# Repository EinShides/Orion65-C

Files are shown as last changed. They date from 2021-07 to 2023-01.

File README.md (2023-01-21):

A 65% keyboard PCB that supports standard and arrow key blocker layouts (such as the kbd67) and stepped caps lock. The PCB also features a flex cut for a softer typing experience. Uses USB type C and has a ESD protection diode. PCB is tested and working. A matching case model can be found here via the fusion 360 link: https://a360.co/2X7CGb7 (Though there is a name engraving for myself in the top right that needs to be changed if you don't want it).

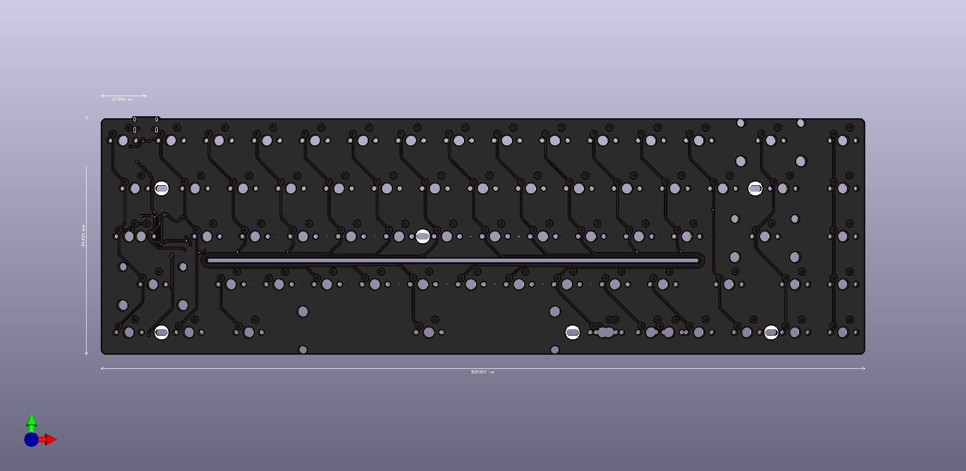
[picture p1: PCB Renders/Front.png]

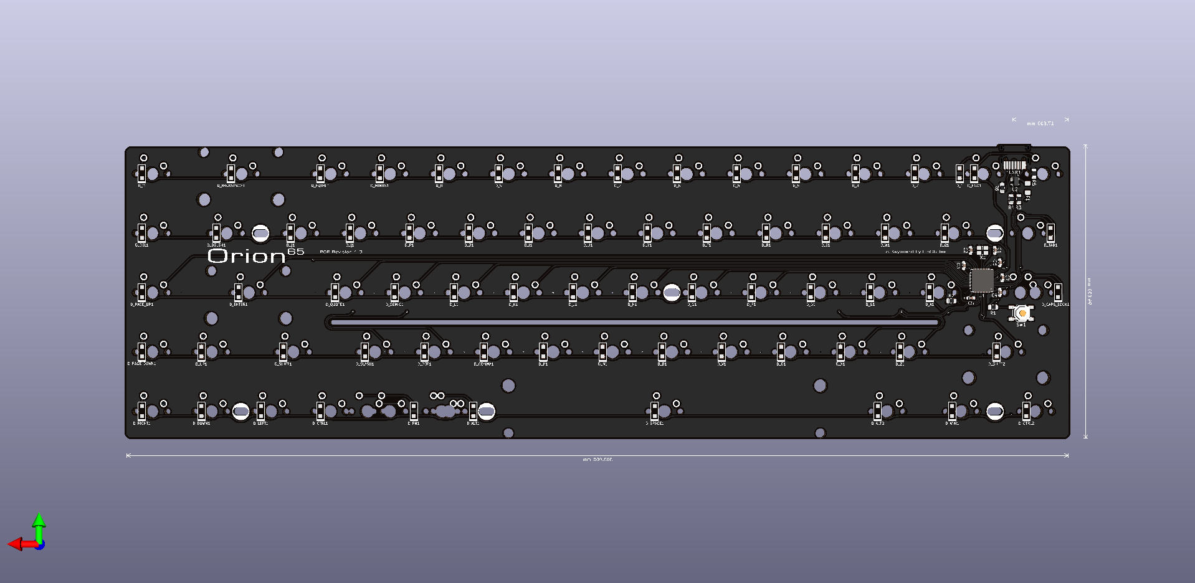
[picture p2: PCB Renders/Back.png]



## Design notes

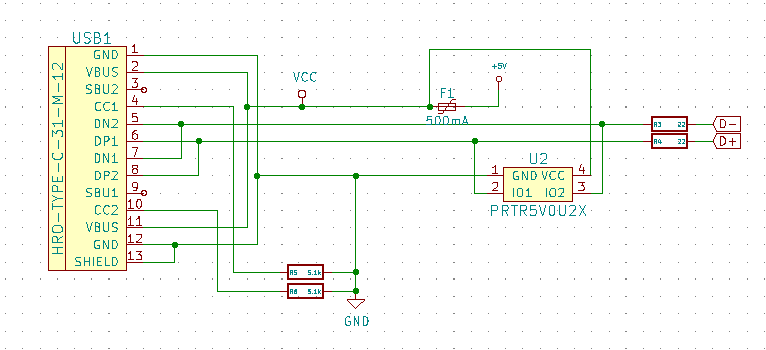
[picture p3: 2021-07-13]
Schematic/Typce C USB.PNG

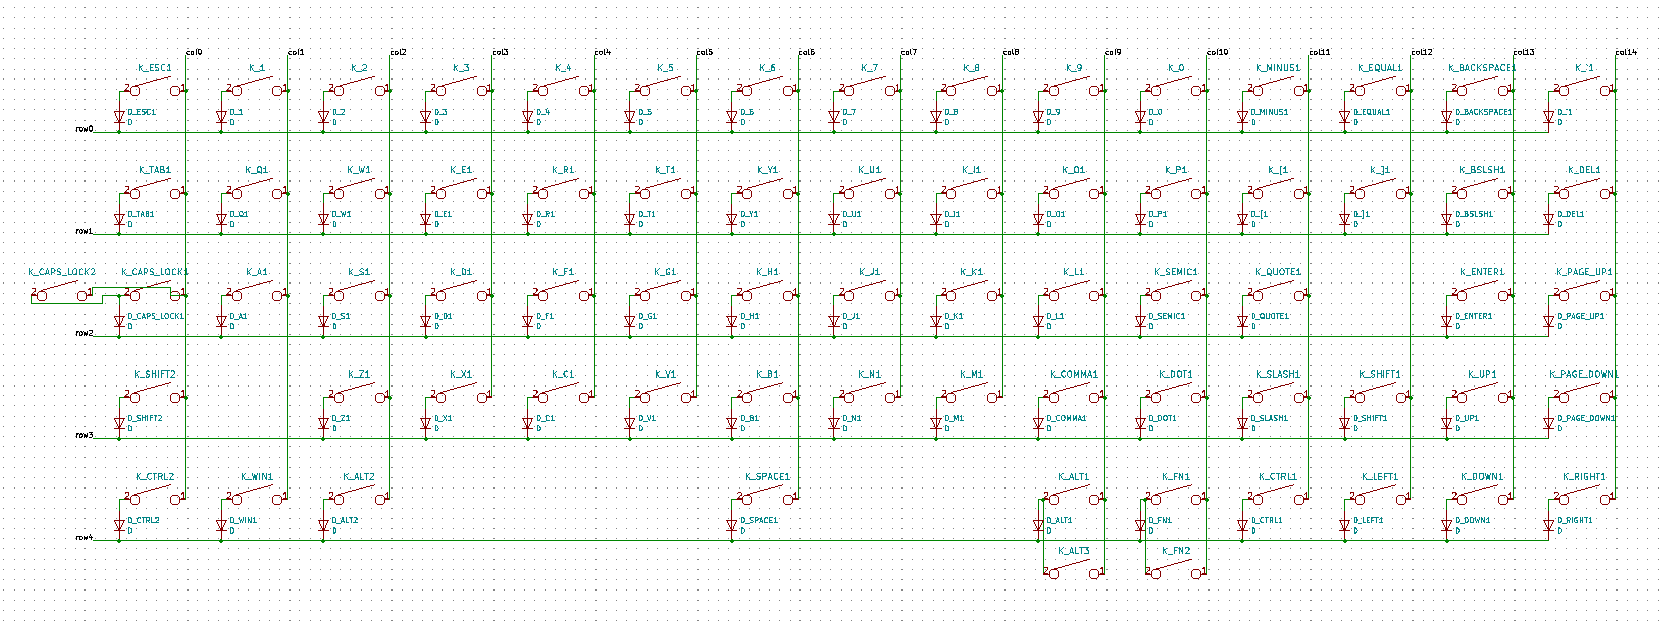
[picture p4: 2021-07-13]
Schematic/Switch Matrix.PNG

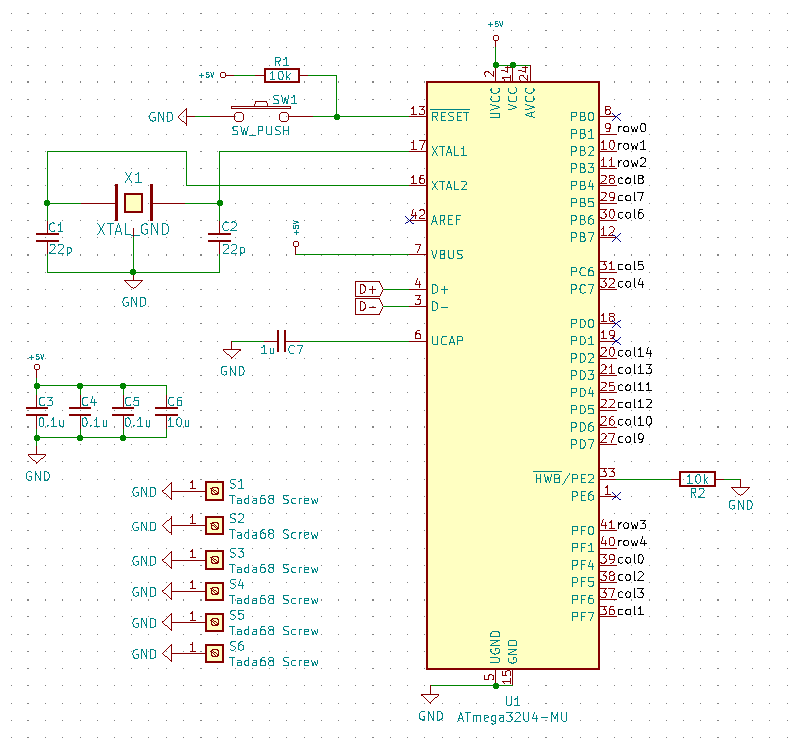
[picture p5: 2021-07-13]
Schematic/MCU.PNG

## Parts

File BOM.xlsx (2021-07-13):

PCB Part Reference | Quantity per PCB | Component | Footprint | Manufacturer | Manufacturer Part Number | Description
U1 | 1 | Atmega32U4-MU Microcontroller | QFN-44-1EP_7x7mm_P0.5mm_EP5.2x5.2mm | Microchip Technology | ATMEGA32U4-MU | AVR AVR® ATmega Microcontroller IC 8-Bit 16MHz 32KB (16K x 16) FLASH 44-VQFN (7x7)
U2 | 1 | PRTR5V0U2X ESD Protection IC | SOT143B | Nexperia USA Inc. | PRTR5V0U2X,215 | Clamp Ipp Tvs Diode Surface Mount SOT-143B
X1 | 1 | Crystal, 3.2 x 2.5mm, 16MHz | crystal_FA238-TSX3225 | EPSON | FA-238 16.0000MB-C3 | 16MHz ±50ppm Crystal 18pF 80 Ohms 4-SMD, No Lead
F1 | 1 | Polyfuse, 500mA hold, 1A trip | Fuse_1206_3216Metric_Pad1.42x1.75mm_HandSolder | Littelfuse Inc. | 1206L050/24WR | Polymeric PTC Resettable Fuse 24V 500mA Ih Surface Mount 1206 (3216 Metric), Concave
USB1 | 1 | USB Type C Port (One Row Design) | HRO-TYPE-C-31-M-12-HandSoldering | Korean Hroparts Elec | TYPE-C-31-M-12 | Type C Female 24 8.94*7.3mm USB Connectors RoHS
C1, C2 | 2 | 22pF Capacitor, Ceramic, 15V or more | C_0603_1608Metric_Pad1.05x0.95mm_HandSolder | Yageo | CC0603JRNPO9BN220 | 22pF ±5% 50V Ceramic Capacitor C0G, NP0 0603 (1608 Metric)
C3, C5, C6 | 4 | 0.1uF (100nF) Capacitor, Ceramic, 15V or more | C_0603_1608Metric_Pad1.05x0.95mm_HandSolder | KEMET | C0603C104J4RACTU | 0.1µF ±5% 16V Ceramic Capacitor X7R 0603 (1608 Metric)
C7 | 1 | 1uF Capacitor, Ceramic, 15V or more | C_0603_1608Metric_Pad1.05x0.95mm_HandSolder | Yageo | CC0603ZRY5V7BB105 | 1µF -20%, +80% 16V Ceramic Capacitor Y5V (F) 0603 (1608 Metric)
C4 | 1 | 10uF Capacitor, Ceramic, 15V or more | C_0603_1608Metric_Pad1.05x0.95mm_HandSolder | Yageo | CC0603MRX5R8BB106 | 10µF ±20% 25V Ceramic Capacitor X5R 0603 (1608 Metric)
R5, R6 | 2 | 5.1k Ohm Resistor, Generic | R_0805_2012Metric_Pad1.15x1.40mm_HandSolder | Bourns Inc. | CR0805-FX-5101ELF | 5.1 kOhms ±1% 0.125W, 1/8W Chip Resistor 0805 (2012 Metric) Moisture Resistant Thick Film
R3, R4 | 2 | 22 Ohm Resistor, Generic | R_0805_2012Metric_Pad1.15x1.40mm_HandSolder | Stackpole Electronics Inc | RMCF0805JT22R0 | 22 Ohms ±5% 0.125W, 1/8W Chip Resistor 0805 (2012 Metric) Automotive AEC-Q200 Thick Film
R1, R2 | 2 | 10k Ohm Resistor, Generic | R_0805_2012Metric_Pad1.15x1.40mm_HandSolder | Stackpole Electronics Inc | RMCF0805JT10K0 | 10 kOhms ±5% 0.125W, 1/8W Chip Resistor 0805 (2012 Metric) Automotive AEC-Q200 Thick Film
All "D" References | 68 | Diode, Generic | D_SOD123_hand | Diodes Incorporated | 1N4148W-13-F | Diode Standard 100V 150mA Surface Mount SOD-123
SW1 | 1 | Button | SW_SPST_TL3342 | E-Switch | TL3342F260QG | Tactile Switch SPST-NO Top Actuated Surface Mount

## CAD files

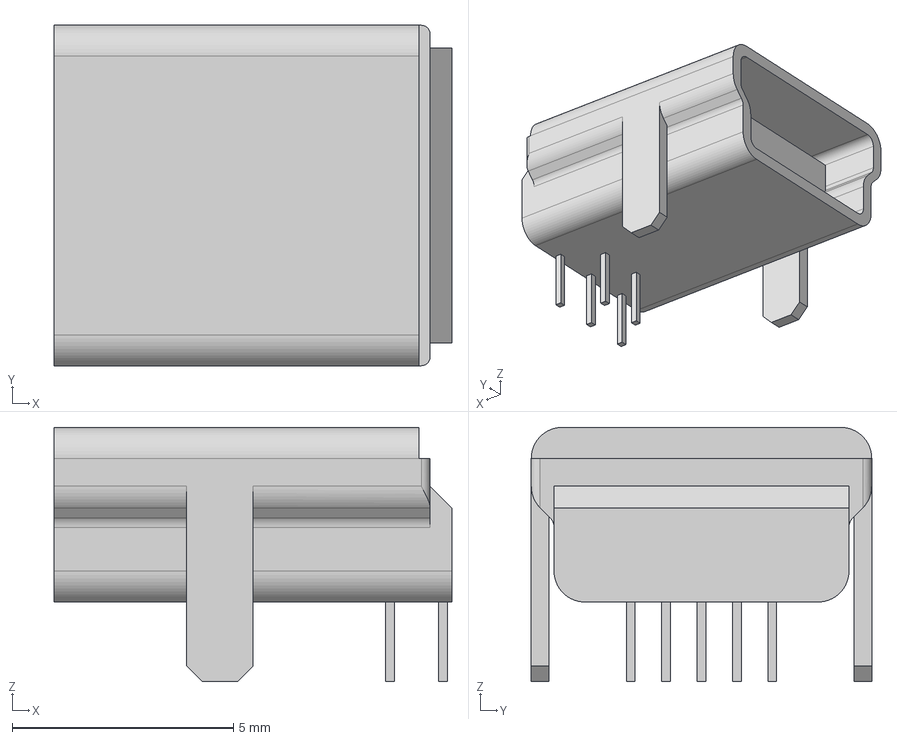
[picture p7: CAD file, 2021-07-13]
random-keyboard-parts.pretty-master/Molex-0548190519.step
9.00 x 7.70 x 5.75 mm

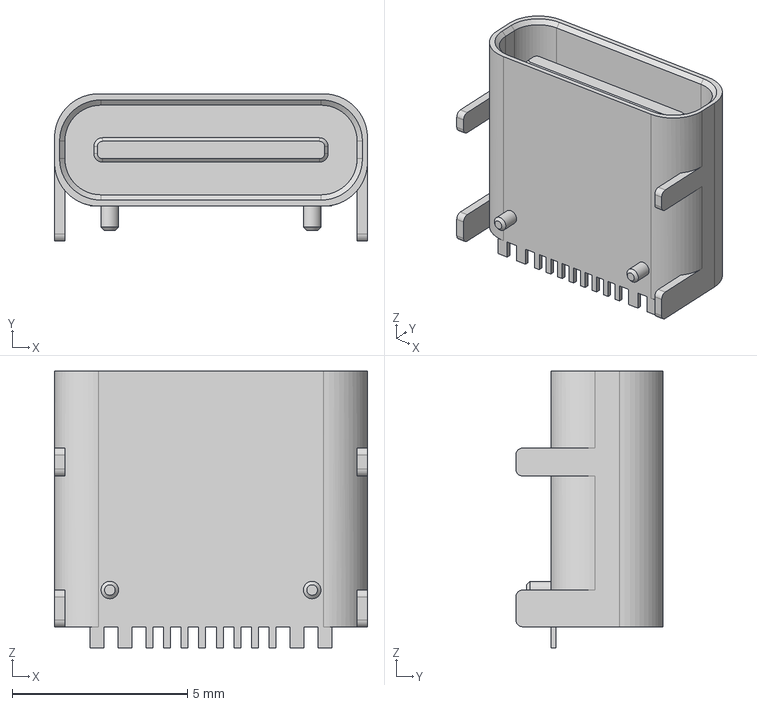
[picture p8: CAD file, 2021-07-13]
Type-C.pretty-master/HRO TYPE-C-31-M-12.step
8.94 x 4.21 x 7.90 mm

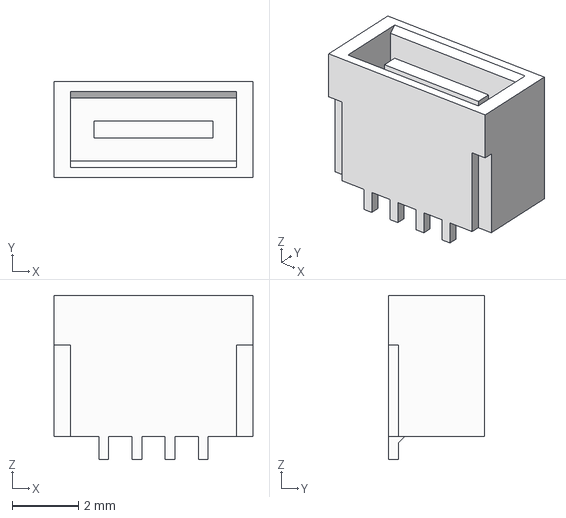
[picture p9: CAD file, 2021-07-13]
random-keyboard-parts.pretty-master/JST-SR-4.step
6.00 x 2.90 x 4.95 mm

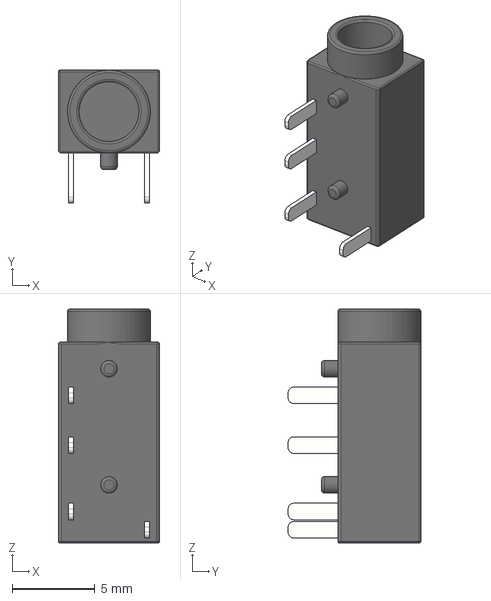
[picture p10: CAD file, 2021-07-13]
random-keyboard-parts.pretty-master/PJ-3200B.step
6.10 x 8.00 x 14.1 mm

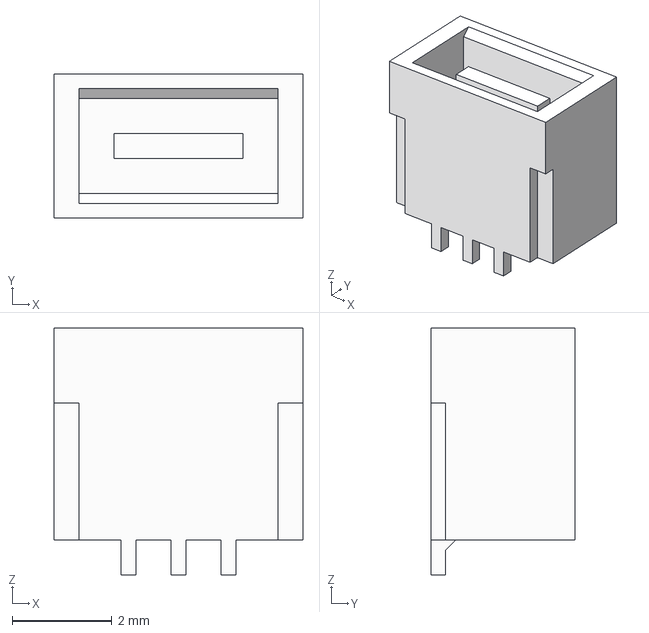
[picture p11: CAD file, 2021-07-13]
random-keyboard-parts.pretty-master/JST-SR-3.step
5.00 x 2.90 x 4.95 mm

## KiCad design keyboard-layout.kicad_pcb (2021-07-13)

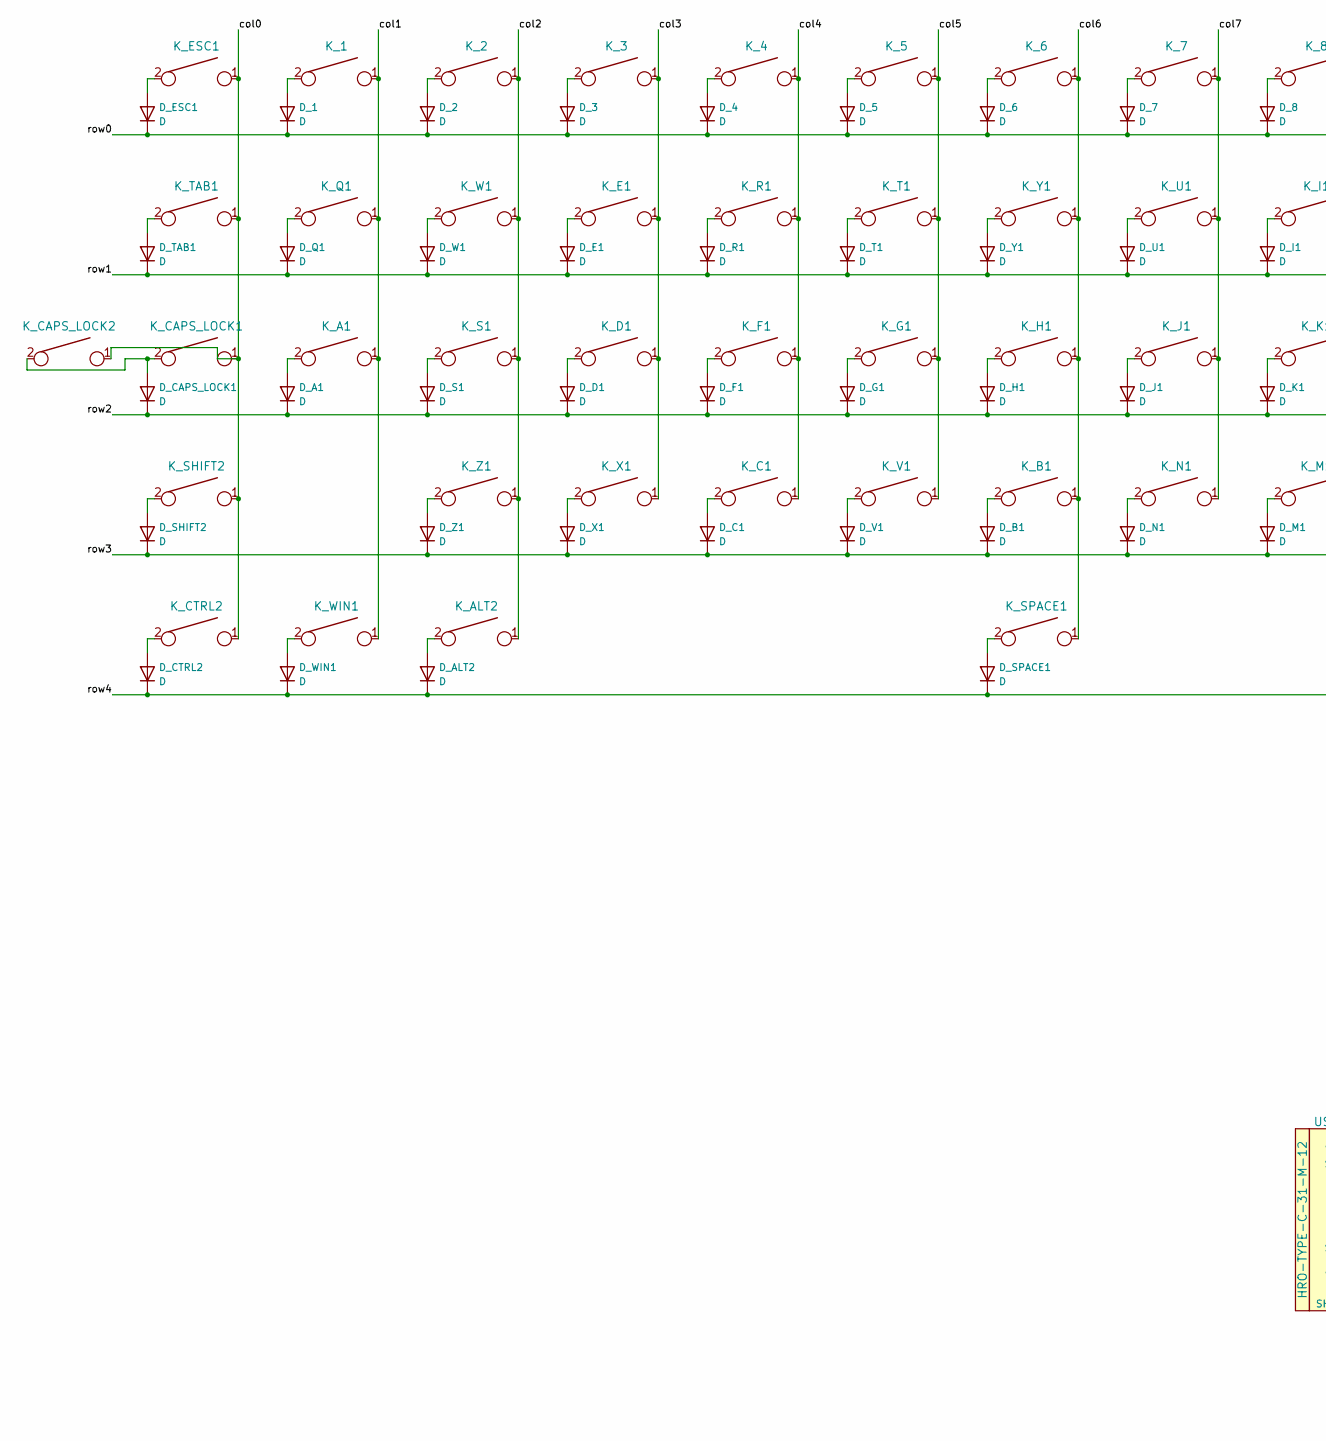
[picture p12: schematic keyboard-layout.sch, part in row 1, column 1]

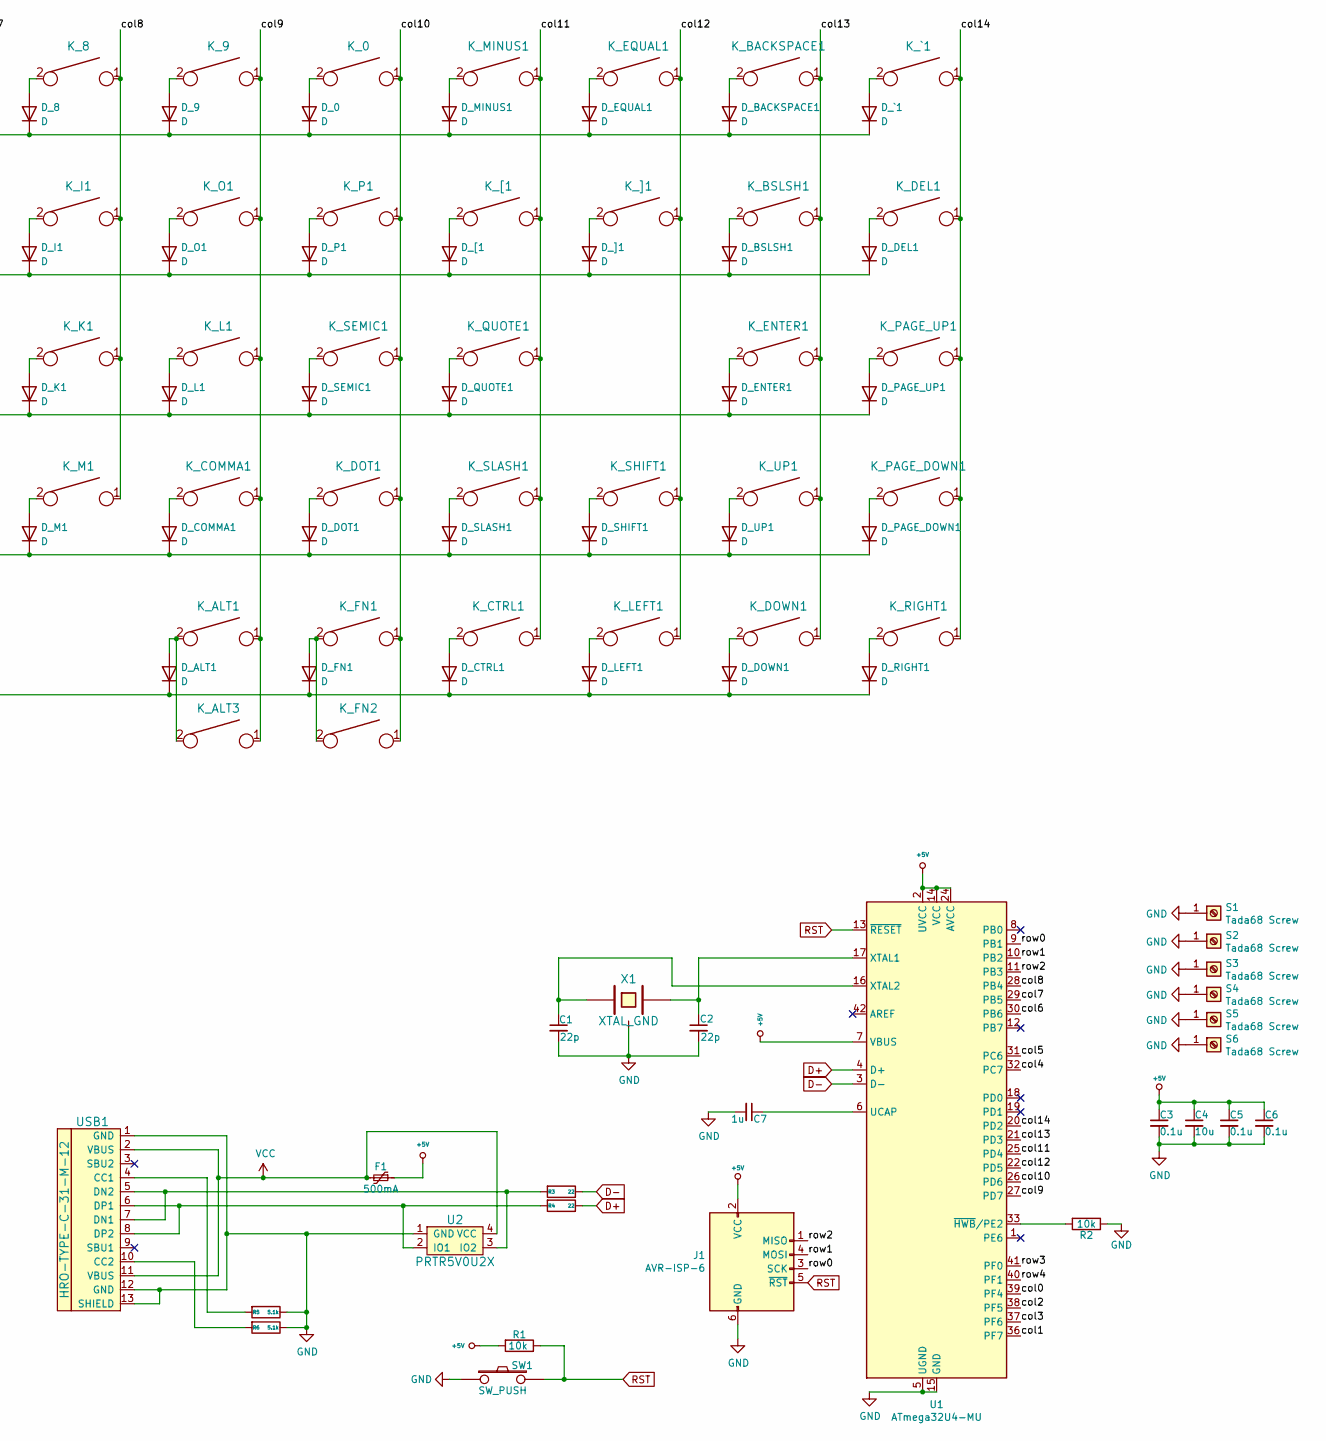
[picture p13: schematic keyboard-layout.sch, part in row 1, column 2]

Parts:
C1, C2: 22p; C_0603_1608Metric_Pad1.05x0.95mm_HandSolder; LCSC C1653
C3, C5, C6: 0.1u; C_0603_1608Metric_Pad1.05x0.95mm_HandSolder; LCSC C24452
C4: 10u; C_0603_1608Metric_Pad1.05x0.95mm_HandSolder; LCSC C96446
C7: 1u; C_0603_1608Metric_Pad1.05x0.95mm_HandSolder; LCSC C15849
D_0, D_1, D_2, D_3, D_4, D_5, D_6, D_7, D_8, D_9: D; D_SOD123_hand; LCSC C64898
D_A1: D; D_SOD123_hand; LCSC C64898
D_ALT1, D_ALT2: D; D_SOD123_hand; LCSC C64898
D_B1: D; D_SOD123_hand; LCSC C64898
D_BACKSPACE1: D; D_SOD123_hand; LCSC C64898
D_BSLSH1: D; D_SOD123_hand; LCSC C64898
D_C1: D; D_SOD123_hand; LCSC C64898
D_CAPS_LOCK1: D; D_SOD123_hand; LCSC C64898
D_COMMA1: D; D_SOD123_hand; LCSC C64898
D_CTRL1, D_CTRL2: D; D_SOD123_hand; LCSC C64898
D_D1: D; D_SOD123_hand; LCSC C64898
D_DEL1: D; D_SOD123_hand; LCSC C64898
D_DOT1: D; D_SOD123_hand; LCSC C64898
D_DOWN1: D; D_SOD123_hand; LCSC C64898
D_E1: D; D_SOD123_hand; LCSC C64898
D_ENTER1: D; D_SOD123_hand; LCSC C64898
D_EQUAL1: D; D_SOD123_hand; LCSC C64898
D_ESC1: D; D_SOD123_hand; LCSC C64898
D_F1: D; D_SOD123_hand; LCSC C64898
D_FN1: D; D_SOD123_hand; LCSC C64898
D_G1: D; D_SOD123_hand; LCSC C64898
D_H1: D; D_SOD123_hand; LCSC C64898
D_I1: D; D_SOD123_hand; LCSC C64898
D_J1: D; D_SOD123_hand; LCSC C64898
D_K1: D; D_SOD123_hand; LCSC C64898
D_L1: D; D_SOD123_hand; LCSC C64898
D_LEFT1: D; D_SOD123_hand; LCSC C64898
D_M1: D; D_SOD123_hand; LCSC C64898
D_MINUS1: D; D_SOD123_hand; LCSC C64898
D_N1: D; D_SOD123_hand; LCSC C64898
D_O1: D; D_SOD123_hand; LCSC C64898
D_P1: D; D_SOD123_hand; LCSC C64898
D_PAGE_DOWN1: D; D_SOD123_hand; LCSC C64898
D_PAGE_UP1: D; D_SOD123_hand; LCSC C64898
D_Q1: D; D_SOD123_hand; LCSC C64898
D_QUOTE1: D; D_SOD123_hand; LCSC C64898
D_R1: D; D_SOD123_hand; LCSC C64898
D_RIGHT1: D; D_SOD123_hand; LCSC C64898
D_S1: D; D_SOD123_hand; LCSC C64898
D_SEMIC1: D; D_SOD123_hand; LCSC C64898
D_SHIFT1, D_SHIFT2: D; D_SOD123_hand; LCSC C64898
D_SLASH1: D; D_SOD123_hand; LCSC C64898
D_SPACE1: D; D_SOD123_hand; LCSC C64898
D_T1: D; D_SOD123_hand; LCSC C64898
D_TAB1: D; D_SOD123_hand; LCSC C64898
D_U1: D; D_SOD123_hand; LCSC C64898
D_UP1: D; D_SOD123_hand; LCSC C64898
D_V1: D; D_SOD123_hand; LCSC C64898
D_W1: D; D_SOD123_hand; LCSC C64898
D_WIN1: D; D_SOD123_hand; LCSC C64898
D_X1: D; D_SOD123_hand; LCSC C64898
D_Y1: D; D_SOD123_hand; LCSC C64898
D_Z1: D; D_SOD123_hand; LCSC C64898
D_[1: D; D_SOD123_hand; LCSC C64898
D_]1: D; D_SOD123_hand; LCSC C64898
D_`1: D; D_SOD123_hand; LCSC C64898
F1: 500mA; Fuse_1206_3216Metric_Pad1.42x1.75mm_HandSolder; LCSC C70076
J1: AVR-ISP-6; isp_standard
K_0, K_1, K_2, K_3, K_4, K_5, K_6, K_7, K_8, K_9: KEYSW; MXOnly-1U-NoLED
K_A1: KEYSW; MXOnly-1U-NoLED
K_ALT1: KEYSW; MXOnly-1U-NoLED
K_ALT2, K_ALT3: KEYSW; MXOnly-1.25U-NoLED
K_B1: KEYSW; MXOnly-1U-NoLED
K_BACKSPACE1: KEYSW; MXOnly-2U-NoLED
K_BSLSH1: KEYSW; MXOnly-1.5U-NoLED
K_C1: KEYSW; MXOnly-1U-NoLED
K_CAPS_LOCK1: KEYSW; MXOnly-1.75U-NoLED
K_CAPS_LOCK2: KEYSW; MXOnly-1.25U-NoLED
K_COMMA1: KEYSW; MXOnly-1U-NoLED
K_CTRL1: KEYSW; MXOnly-1U-NoLED
K_CTRL2: KEYSW; MXOnly-1.25U-NoLED
K_D1: KEYSW; MXOnly-1U-NoLED
K_DEL1: KEYSW; MXOnly-1U-NoLED
K_DOT1: KEYSW; MXOnly-1U-NoLED
K_DOWN1: KEYSW; MXOnly-1U-NoLED
K_E1: KEYSW; MXOnly-1U-NoLED
K_ENTER1: KEYSW; MXOnly-2.25U-NoLED
K_EQUAL1: KEYSW; MXOnly-1U-NoLED
K_ESC1: KEYSW; MXOnly-1U-NoLED
K_F1: KEYSW; MXOnly-1U-NoLED
K_FN1: KEYSW; MXOnly-1U-NoLED
K_FN2: KEYSW; MXOnly-1.25U-NoLED
K_G1: KEYSW; MXOnly-1U-NoLED
K_H1: KEYSW; MXOnly-1U-NoLED
K_I1: KEYSW; MXOnly-1U-NoLED
K_J1: KEYSW; MXOnly-1U-NoLED
K_K1: KEYSW; MXOnly-1U-NoLED
K_L1: KEYSW; MXOnly-1U-NoLED
K_LEFT1: KEYSW; MXOnly-1U-NoLED
K_M1: KEYSW; MXOnly-1U-NoLED
K_MINUS1: KEYSW; MXOnly-1U-NoLED
K_N1: KEYSW; MXOnly-1U-NoLED
K_O1: KEYSW; MXOnly-1U-NoLED
K_P1: KEYSW; MXOnly-1U-NoLED
K_PAGE_DOWN1: KEYSW; MXOnly-1U-NoLED
K_PAGE_UP1: KEYSW; MXOnly-1U-NoLED
K_Q1: KEYSW; MXOnly-1U-NoLED
K_QUOTE1: KEYSW; MXOnly-1U-NoLED
K_R1: KEYSW; MXOnly-1U-NoLED
K_RIGHT1: KEYSW; MXOnly-1U-NoLED
K_S1: KEYSW; MXOnly-1U-NoLED
K_SEMIC1: KEYSW; MXOnly-1U-NoLED
K_SHIFT1: KEYSW; MXOnly-1.75U-NoLED
K_SHIFT2: KEYSW; MXOnly-2.25U-NoLED
K_SLASH1: KEYSW; MXOnly-1U-NoLED
K_SPACE1: KEYSW; MXOnly-6.25U-ReversedStabilizers-NoLED
K_T1: KEYSW; MXOnly-1U-NoLED
K_TAB1: KEYSW; MXOnly-1.5U-NoLED
K_U1: KEYSW; MXOnly-1U-NoLED
K_UP1: KEYSW; MXOnly-1U-NoLED
K_V1: KEYSW; MXOnly-1U-NoLED
K_W1: KEYSW; MXOnly-1U-NoLED
K_WIN1: KEYSW; MXOnly-1.25U-NoLED
K_X1: KEYSW; MXOnly-1U-NoLED
K_Y1: KEYSW; MXOnly-1U-NoLED
K_Z1: KEYSW; MXOnly-1U-NoLED
K_[1: KEYSW; MXOnly-1U-NoLED
K_]1: KEYSW; MXOnly-1U-NoLED
K_`1: KEYSW; MXOnly-1U-NoLED
R1, R2: 10k; R_0805_2012Metric_Pad1.15x1.40mm_HandSolder; LCSC C17414
R3, R4: 22; R_0805_2012Metric_Pad1.15x1.40mm_HandSolder; LCSC C17561
R5, R6: 5.1k; R_0805_2012Metric_Pad1.15x1.40mm_HandSolder; LCSC C27834
S1, S2, S3, S4, S5, S6: Tada68 Screw; 5.5_5x2.5mm
SW1: SW_PUSH; SW_SPST_TL3342
U1: ATmega32U4-MU; QFN-44-1EP_7x7mm_P0.5mm_EP5.2x5.2mm; LCSC C45874
U2: PRTR5V0U2X; SOT143B; LCSC C316030
USB1: HRO-TYPE-C-31-M-12; HRO-TYPE-C-31-M-12-HandSoldering; LCSC C165948
X1: XTAL_GND; crystal_FA238-TSX3225; LCSC C89371

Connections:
+5V: C3.1, C4.1, C5.1, C6.1, F1.1, J1.2 (VCC), R1.2, U1.2 (UVCC), U1.7 (VBUS), U1.14 (VCC), U1.24 (AVCC), U1.34 (VCC), U1.44 (AVCC)
/col0: K_CAPS_LOCK1.1, K_CAPS_LOCK2.1, K_CTRL2.1, K_ESC1.1, K_SHIFT2.1, K_TAB1.1, U1.39 (PF4)
/col1: K_1.1, K_A1.1, K_Q1.1, K_WIN1.1, U1.36 (PF7)
/col2: K_2.1, K_ALT2.1, K_S1.1, K_W1.1, K_Z1.1, U1.38 (PF5)
/col3: K_3.1, K_D1.1, K_E1.1, K_X1.1, U1.37 (PF6)
/col4: K_4.1, K_C1.1, K_F1.1, K_R1.1, U1.32 (PC7)
/col5: K_5.1, K_G1.1, K_T1.1, K_V1.1, U1.31 (PC6)
/col6: K_6.1, K_B1.1, K_H1.1, K_SPACE1.1, K_Y1.1, U1.30 (PB6)
/col7: K_7.1, K_J1.1, K_N1.1, K_U1.1, U1.29 (PB5)
/col8: K_8.1, K_I1.1, K_K1.1, K_M1.1, U1.28 (PB4)
/col9: K_9.1, K_ALT1.1, K_ALT3.1, K_COMMA1.1, K_L1.1, K_O1.1, U1.27 (PD7)
/col10: K_0.1, K_DOT1.1, K_FN1.1, K_FN2.1, K_P1.1, K_SEMIC1.1, U1.26 (PD6)
/col11: K_CTRL1.1, K_MINUS1.1, K_QUOTE1.1, K_SLASH1.1, K_[1.1, U1.25 (PD4)
/col12: K_EQUAL1.1, K_LEFT1.1, K_SHIFT1.1, K_]1.1, U1.22 (PD5)
/col13: K_BACKSPACE1.1, K_BSLSH1.1, K_DOWN1.1, K_ENTER1.1, K_UP1.1, U1.21 (PD3)
/col14: K_DEL1.1, K_PAGE_DOWN1.1, K_PAGE_UP1.1, K_RIGHT1.1, K_`1.1, U1.20 (PD2)
/row0: D_0.1 (K), D_1.1 (K), D_2.1 (K), D_3.1 (K), D_4.1 (K), D_5.1 (K), D_6.1 (K), D_7.1 (K), D_8.1 (K), D_9.1 (K), D_BACKSPACE1.1 (K), D_EQUAL1.1 (K), D_ESC1.1 (K), D_MINUS1.1 (K), D_`1.1 (K), J1.3 (SCK), U1.9 (PB1)
/row1: D_BSLSH1.1 (K), D_DEL1.1 (K), D_E1.1 (K), D_I1.1 (K), D_O1.1 (K), D_P1.1 (K), D_Q1.1 (K), D_R1.1 (K), D_T1.1 (K), D_TAB1.1 (K), D_U1.1 (K), D_W1.1 (K), D_Y1.1 (K), D_[1.1 (K), D_]1.1 (K), J1.4 (MOSI), U1.10 (PB2)
/row2: D_A1.1 (K), D_CAPS_LOCK1.1 (K), D_D1.1 (K), D_ENTER1.1 (K), D_F1.1 (K), D_G1.1 (K), D_H1.1 (K), D_J1.1 (K), D_K1.1 (K), D_L1.1 (K), D_PAGE_UP1.1 (K), D_QUOTE1.1 (K), D_S1.1 (K), D_SEMIC1.1 (K), J1.1 (MISO), U1.11 (PB3)
/row3: D_B1.1 (K), D_C1.1 (K), D_COMMA1.1 (K), D_DOT1.1 (K), D_M1.1 (K), D_N1.1 (K), D_PAGE_DOWN1.1 (K), D_SHIFT1.1 (K), D_SHIFT2.1 (K), D_SLASH1.1 (K), D_UP1.1 (K), D_V1.1 (K), D_X1.1 (K), D_Z1.1 (K), U1.41 (PF0)
/row4: D_ALT1.1 (K), D_ALT2.1 (K), D_CTRL1.1 (K), D_CTRL2.1 (K), D_DOWN1.1 (K), D_FN1.1 (K), D_LEFT1.1 (K), D_RIGHT1.1 (K), D_SPACE1.1 (K), D_WIN1.1 (K), U1.40 (PF1)
D+: R4.1, U1.4 (D+)
D-: R3.1, U1.3 (D-)
GND: C1.2, C2.2, C3.2, C4.2, C5.2, C6.2, C7.2, J1.6 (GND), R2.1, R5.1, R6.1, S1.1, S2.1, S3.1, S4.1, S5.1, S6.1, SW1.1, U1.5 (UGND), U1.15 (GND), U1.23 (GND), U1.35 (GND), U1.43 (GND), U1.45 (GND), U2.1 (GND), USB1.1 (GND), USB1.12 (GND), USB1.13 (SHIELD), X1.3
unnamed: C1.1, U1.16 (XTAL2), X1.1
unnamed: C2.1, U1.17 (XTAL1), X1.2
unnamed: C7.1, U1.6 (UCAP)
unnamed: D_0.2 (A), K_0.2
unnamed: D_1.2 (A), K_1.2
unnamed: D_2.2 (A), K_2.2
unnamed: D_3.2 (A), K_3.2
unnamed: D_4.2 (A), K_4.2
unnamed: D_5.2 (A), K_5.2
unnamed: D_6.2 (A), K_6.2
unnamed: D_7.2 (A), K_7.2
unnamed: D_8.2 (A), K_8.2
unnamed: D_9.2 (A), K_9.2
unnamed: D_A1.2 (A), K_A1.2
unnamed: D_ALT1.2 (A), K_ALT1.2, K_ALT3.2
unnamed: D_ALT2.2 (A), K_ALT2.2
unnamed: D_B1.2 (A), K_B1.2
unnamed: D_BACKSPACE1.2 (A), K_BACKSPACE1.2
unnamed: D_BSLSH1.2 (A), K_BSLSH1.2
unnamed: D_C1.2 (A), K_C1.2
unnamed: D_CAPS_LOCK1.2 (A), K_CAPS_LOCK1.2, K_CAPS_LOCK2.2
unnamed: D_COMMA1.2 (A), K_COMMA1.2
unnamed: D_CTRL1.2 (A), K_CTRL1.2
unnamed: D_CTRL2.2 (A), K_CTRL2.2
unnamed: D_D1.2 (A), K_D1.2
unnamed: D_DEL1.2 (A), K_DEL1.2
unnamed: D_DOT1.2 (A), K_DOT1.2
unnamed: D_DOWN1.2 (A), K_DOWN1.2
unnamed: D_E1.2 (A), K_E1.2
unnamed: D_ENTER1.2 (A), K_ENTER1.2
unnamed: D_EQUAL1.2 (A), K_EQUAL1.2
unnamed: D_ESC1.2 (A), K_ESC1.2
unnamed: D_F1.2 (A), K_F1.2
unnamed: D_FN1.2 (A), K_FN1.2, K_FN2.2
unnamed: D_G1.2 (A), K_G1.2
unnamed: D_H1.2 (A), K_H1.2
unnamed: D_I1.2 (A), K_I1.2
unnamed: D_J1.2 (A), K_J1.2
unnamed: D_K1.2 (A), K_K1.2
unnamed: D_L1.2 (A), K_L1.2
unnamed: D_LEFT1.2 (A), K_LEFT1.2
unnamed: D_M1.2 (A), K_M1.2
unnamed: D_MINUS1.2 (A), K_MINUS1.2
unnamed: D_N1.2 (A), K_N1.2
unnamed: D_O1.2 (A), K_O1.2
unnamed: D_P1.2 (A), K_P1.2
unnamed: D_PAGE_DOWN1.2 (A), K_PAGE_DOWN1.2
unnamed: D_PAGE_UP1.2 (A), K_PAGE_UP1.2
unnamed: D_Q1.2 (A), K_Q1.2
unnamed: D_QUOTE1.2 (A), K_QUOTE1.2
unnamed: D_R1.2 (A), K_R1.2
unnamed: D_RIGHT1.2 (A), K_RIGHT1.2
unnamed: D_S1.2 (A), K_S1.2
unnamed: D_SEMIC1.2 (A), K_SEMIC1.2
unnamed: D_SHIFT1.2 (A), K_SHIFT1.2
unnamed: D_SHIFT2.2 (A), K_SHIFT2.2
unnamed: D_SLASH1.2 (A), K_SLASH1.2
unnamed: D_SPACE1.2 (A), K_SPACE1.2
unnamed: D_T1.2 (A), K_T1.2
unnamed: D_TAB1.2 (A), K_TAB1.2
unnamed: D_U1.2 (A), K_U1.2
unnamed: D_UP1.2 (A), K_UP1.2
unnamed: D_V1.2 (A), K_V1.2
unnamed: D_W1.2 (A), K_W1.2
unnamed: D_WIN1.2 (A), K_WIN1.2
unnamed: D_X1.2 (A), K_X1.2
unnamed: D_Y1.2 (A), K_Y1.2
unnamed: D_Z1.2 (A), K_Z1.2
unnamed: D_[1.2 (A), K_[1.2
unnamed: D_]1.2 (A), K_]1.2
unnamed: D_`1.2 (A), K_`1.2
unnamed: R2.2, U1.33 (~HWB~/PE2)
unnamed: R3.2, U2.3 (IO2), USB1.5 (DN2), USB1.7 (DN1)
unnamed: R4.2, U2.2 (IO1), USB1.6 (DP1), USB1.8 (DP2)
unnamed: R5.2, USB1.4 (CC1)
unnamed: R6.2, USB1.10 (CC2)
RST: J1.5 (~RST), R1.1, SW1.2, U1.13 (~RESET)
VCC: F1.2, U2.4 (VCC), USB1.2 (VBUS), USB1.11 (VBUS)

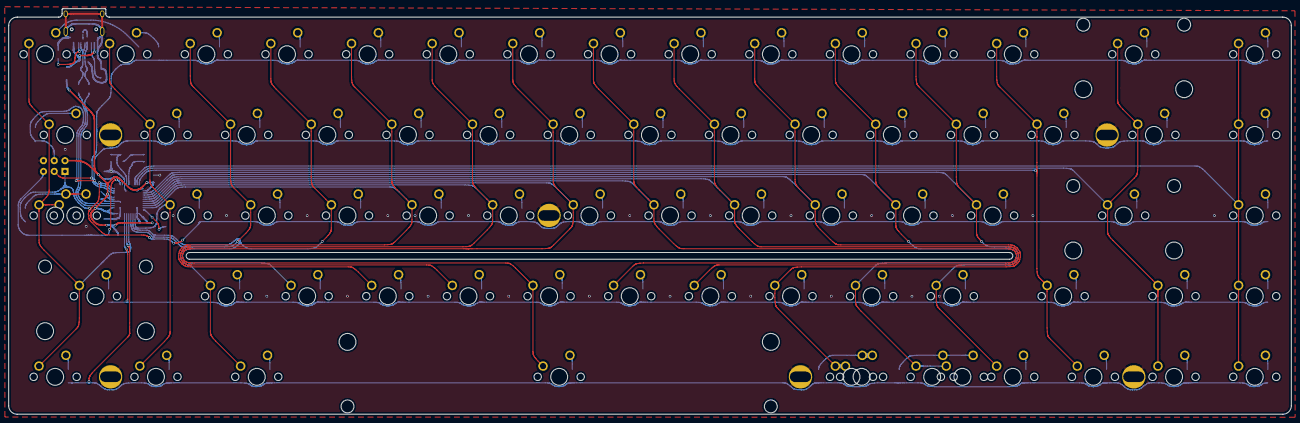
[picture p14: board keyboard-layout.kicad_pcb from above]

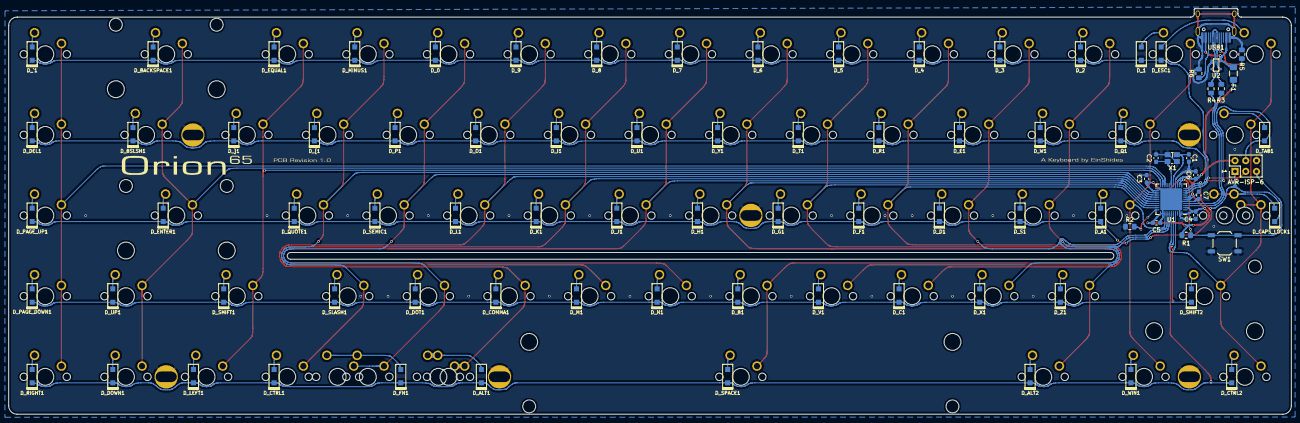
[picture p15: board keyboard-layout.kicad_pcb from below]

Board: 2 copper layers, 303.0 x 95.8 mm, 165 parts (88 on the bottom side), 102 nets.
